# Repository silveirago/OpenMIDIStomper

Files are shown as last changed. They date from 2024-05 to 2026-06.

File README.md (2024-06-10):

# OpenMIDIStomper

## Description
_openMIDIStomper is an Arduino-based MIDI foot controller that provides customizable MIDI message sending capabilities using buttons, potentiometers, and LEDs. It can control any DAW plugin since it's USB MIDI Class compliant. It features 8 stomp buttons and 8 LEDs, all housed in a Hammond aluminum enclosure. The pedalboard has 8 banks, and each button can send up to 5 different messages, configurable through a browser editor.

## Features
- **Button Control:** Send MIDI messages using button presses.
- **Potentiometer Control:** Adjust MIDI parameters with potentiometers.
- **LED Indicators:** Visual feedback using LEDs.
- **Customizable Messages:** Define your own MIDI messages and configurations.

## Watch the Youtube video here:
[Link](https://youtu.be/yELnZdEJqS0)

## Material
 - [1x Arduino Pro Micro](https://amzn.to/3Vg9KrE)
 - [1x Solderable Breadboard](https://amzn.to/4egjUB1)
 - [8x Stomp Buttons](https://amzn.to/3V9GrXu)
 - [8x 5mm Leds](https://amzn.to/3xiPGN9) 
 - [8x 5mm LED Holders](https://amzn.to/4aT8Reh)
 - [2x 1/4" Stereo Socket](https://amzn.to/4aYbtaX)
 - [1x Hammond Enclosure](https://www.aliexpress.us/item/3256805426594939.html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)

## Getting Started

### Prerequisites
- Arduino IDE installed on your computer.
- Arduino board (compatible with the code).
- Necessary components:
  - Push buttons
  - Potentiometers
  - LEDs
  - Resistors
  - Breadboard and jumper wires

### Installation

1. **Clone the Repository:**
   ```sh
   git clone https://github.com/yourusername/_openMIDIStomper.git
   ```

2. **Open the Project:**
   Open the `_openMIDIStomper.ino` file in the Arduino IDE.

## Hardware Setup

### Components and Connections
1. **Buttons:**
   - Connect one terminal of each button in the first row to pin 15.
   - Connect one terminal of each button in the second row to pin 14.
   - Connect the other terminal of the first button in each column to pin 21.
   - Connect the other terminal of the second button in each column to pin 20.
   - Connect the other terminal of the third button in each column to pin 19.
   - Connect the other terminal of the fourth button in each column to pin 16.

2. **Potentiometers:**
   - Connect the middle terminal of each potentiometer to an analog input pin on the Arduino.
   - Connect the other two terminals to 5V and ground, respectively.

3. **LEDs:**

   - **Pins**:  2, 3, 4, 5, 6, 7, 8, 9

#### Connecting LEDs

- **LED 1 (D1)**: Connect the anode to pin 2 through a 220Ω resistor and the cathode to ground.
- **LED 2 (D2)**: Connect the anode to pin 3 through a 220Ω resistor and the cathode to ground.
- **LED 3 (D3)**: Connect the anode to pin 4 through a 220Ω resistor and the cathode to ground.
- **LED 4 (D4)**: Connect the anode to pin 5 through a 220Ω resistor and the cathode to ground.
- **LED 5 (D5)**: Connect the anode to pin 6 through a 220Ω resistor and the cathode to ground.
- **LED 6 (D6)**: Connect the anode to pin 7 through a 220Ω resistor and the cathode to ground.
- **LED 7 (D7)**: Connect the anode to pin 8 through a 220Ω resistor and the cathode to ground.
- **LED 8 (D8)**: Connect the anode to pin 9 through a 220Ω resistor and the cathode to ground.

### Button Matrix

#### Pins Used
- **Rows**: Pins 15 and 14
- **Columns**: Pins 21, 20, 19, and 16

#### Wiring Diagram

- **Button 1 (B1)**: Connect one terminal to pin 15 (Row1) and the other terminal to pin 21 (Column1).
- **Button 2 (B2)**: Connect one terminal to pin 15 (Row1) and the other terminal to pin 20 (Column2).
- **Button 3 (B3)**: Connect one terminal to pin 15 (Row1) and the other terminal to pin 19 (Column3).
- **Button 4 (B4)**: Connect one terminal to pin 15 (Row1) and the other terminal to pin 16 (Column4).

- **Button 5 (B5)**: Connect one terminal to pin 14 (Row2) and the other terminal to pin 21 (Column1).
- **Button 6 (B6)**: Connect one terminal to pin 14 (Row2) and the other terminal to pin 20 (Column2).
- **Button 7 (B7)**: Connect one terminal to pin 14 (Row2) and the other terminal to pin 19 (Column3).
- **Button 8 (B8)**: Connect one terminal to pin 14 (Row2) and the other terminal to pin 16 (Column4).

### Software Configuration

1. **Button Definitions:**
   - Modify `ButtonDefinitions.h` to define the pins and settings for your buttons.

2. **Button Logic:**
   - Implement the logic for button presses in `ButtonLogic.h`.

3. **LED Control:**
   - Adjust the LED control logic in `LEDControl.h`.

4. **MIDI Messages:**
   - Configure the MIDI messages to be sent in `MIDIMessages.h`.

5. **MIDI Out:**
   - Set up the MIDI output in `MIDIOut.h`.

6. **Potentiometer Control:**
   - Define how potentiometer inputs affect MIDI messages in `PotentiometerControl.h`.

## Usage

1. **Upload the Code:**
   - Connect your Arduino board to your computer.
   - Select the appropriate board and port in the Arduino IDE.
   - Upload the `_openMIDIStomper.ino` sketch to the board.

2. **Connect to MIDI Device:**
   - Use a MIDI interface to connect the Arduino to your MIDI device or computer.

3. **Operate:**
   - Press buttons, turn potentiometers, and observe the LED feedback to control your MIDI device.

## Troubleshooting

- Ensure all connections are secure.
- Verify that the correct pins are defined in the header files.
- Check the Arduino IDE for any compilation errors.
- Consult the serial monitor for debugging messages.

## Instructions to Use the MIDI Message Configuration Code Editor

   **Use the editor here**: https://go.musiconerd.com/openmidistomper-editor

1. **Configure the MIDI Messages:**
   - The interface allows you to configure MIDI messages for up to 8 banks, each containing 8 buttons.
   - Each button can send up to 5 different MIDI messages.
   - For each message, you can specify the type (NN, CC, PC, T), the message number (0-127), and the MIDI channel (0-15).

2. **Expand Sections:**
   - Click on the "Bank" buttons to expand and configure each bank.
   - Click on the "Button" buttons within each bank to expand and configure each button's messages.

3. **Pre-fill Values:**
   - By default, the first message for each button is set to Note Number (NN), with the number equal to the button index and the channel equal to the bank index.
   - You can adjust these values as needed.

4. **Copy Configuration:**
   - Once you have configured the MIDI messages, click the "Copy Configuration to Clipboard" button.
   - A message will appear indicating that the configuration has been copied to your clipboard.

5. **Paste into Arduino Sketch:**
   - Open your Arduino sketch in the Arduino IDE.
   - Paste the copied configuration code into the appropriate section of your sketch.

6. **Export and Import Bank Configurations:**
   - To export a bank's configuration, click the "Export Bank Configuration" button for the desired bank. This will download a text file with the configuration.
   - To import a bank's configuration, click the "Import Bank Configuration" button for the desired bank and select the previously exported configuration file.

7. **Save and Upload:**
   - Save the changes in your Arduino sketch.
   - Upload the sketch to your Arduino board to use the configured MIDI messages.

This HTML code editor provides a user-friendly interface to configure and manage MIDI messages, making it easy to set up your MIDI controller.

## How to Upload Your Presets

### Method 1: Using GitHub Issues

1. **Go to the Issues Tab**: Navigate to the Issues tab of the repository.

2. **Create a New Issue**:
    - Click on the "New Issue" button.
    - Provide a descriptive title for your issue, such as "New Preset: [Preset Name]".
    - In the description, provide any relevant details about your preset.

3. **Attach Your Preset File**:
    - Drag and drop your preset file into the issue description area or click the "Attach files by dragging & dropping, selecting or pasting them." link.
    - Ensure the file uploads successfully.

4. **Submit the Issue**:
    - Click the "Submit new issue" button to create the issue.

Thank you! We will review your preset and integrate it into the repository.

### Method 2: Using Pull Requests (Advanced Users)

1. **Fork the Repository**:
    - Click the "Fork" button at the top right of the repository page to create a copy of the repository under your GitHub account.

2. **Clone the Repository**:
    - Clone your forked repository to your local machine using the following command:
      ```sh
      git clone https://github.com/YOUR-USERNAME/REPOSITORY-NAME.git
      ```
    - Replace \`YOUR-USERNAME\` with your GitHub username and \`REPOSITORY-NAME\` with the name of the repository.

3. **Create a New Branch**:
    - Navigate to the repository directory on your local machine:
      ```sh
      cd REPOSITORY-NAME
      ```
    - Create a new branch for your changes:
      ```sh
      git checkout -b new-preset-branch
      ```

4. **Add Your Preset File**:
    - Add your preset file to the appropriate directory (e.g., \`presets/\`):
      ```sh
      cp /path/to/your/preset/file presets/
      ```

5. **Commit Your Changes**:
    - Stage your changes:
      ```sh
      git add presets/your-preset-file
      ```
    - Commit your changes with a descriptive message:
      ```sh
      git commit -m "Add new preset: [Preset Name]"
      ```

6. **Push Your Changes**:
    - Push your changes to your forked repository:
      ```sh
      git push origin new-preset-branch
      ```

7. **Create a Pull Request**:
    - Navigate to your forked repository on GitHub.
    - Click the "Compare & pull request" button next to your new branch.
    - Provide a descriptive title and description for your pull request.
    - Click "Create pull request".

We will review your pull request and merge it if everything looks good. Thank you for your contribution!

Feel free to reach out via the [Discussions] https://github.com/silveirago/OpenMIDIStomper/discussions tab if you have any questions or need further assistance. Happy contributing!

## Contributing

Feel free to contribute to this project by submitting issues or pull requests. Any improvements or bug fixes are welcome.

## License

This project is licensed under the MIT License. See the LICENSE file for details.

## Acknowledgements

Thank you to the open-source community for providing valuable resources and inspiration for this project.

## Support this Project

This project was created by me, Gustavo Silveira, a.k.a. the Nerd Musician, for the community.

If you want to support me, so I can keep doing projects like this, consider buying one of my DIY MIDI Controller courses: https://go.musiconerd.com/nerd-musician-pro

Or PayPal me any ammount here: https://www.paypal.com/paypalme/nerdmusician

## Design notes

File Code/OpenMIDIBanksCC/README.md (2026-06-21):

# OpenMIDIBanksCC

Standalone OpenMIDIStomper firmware variant that preserves the original bank, button, LED, and matrix interaction model while changing only the outgoing MIDI assignments.

## Behavior Summary

- Short press + release sends one CC with value `127`.
- The button action uses the bank that was active when the press started.
- Long press for 1 second selects the corresponding bank.
- Long-press bank selection suppresses the button action.
- Idle LEDs show the active bank exactly like the original firmware.
- `A0` is an optional compile-time expression pedal input.
- `A10` is an optional compile-time sustain pedal input.
- MIDI channel is `16`.

## Hardware Reference

- Rows: `15, 14`
- Columns: `21, 20, 19, 16`
- LEDs: `2, 3, 4, 5, 6, 7, 8, 9`
- Expression: `A0`
- Sustain: optional `A10`
- LEDs are active-high.

Buttons are scanned as a `2x4` matrix with row pins driven `HIGH` at idle and pulled `LOW` one at a time during scan. Column pins use `INPUT_PULLUP`, so a pressed switch reads `LOW`.

## CC Table

| Bank | Buttons | A0 |
|---|---|---|
| 1 | `56, 57, 58, 59, 60, 61, 62, 63` | `64` |
| 2 | `65, 66, 67, 68, 69, 70, 71, 72` | `73` |
| 3 | `74, 75, 76, 77, 78, 79, 80, 81` | `82` |
| 4 | `83, 84, 85, 86, 87, 88, 89, 90` | `91` |
| 5 | `92, 93, 94, 95, 96, 97, 98, 99` | `100` |
| 6 | `101, 102, 103, 104, 105, 106, 107, 108` | `109` |
| 7 | `110, 111, 112, 113, 114, 115, 116, 117` | `118` |
| 8 | `119, 120, 121, 122, 123, 124, 125, 126` | `127` |

## Compile-Time Pedal Options

At the top of the sketch:

```cpp
#define ENABLE_EXPRESSION_A0  1
#define ENABLE_SUSTAIN_A10    1
```

- Enable A0: set `#define ENABLE_EXPRESSION_A0  1`
- Disable A0: set `#define ENABLE_EXPRESSION_A0  0`
- Enable sustain on A10: set `#define ENABLE_SUSTAIN_A10    1`
- Disable sustain on A10: set `#define ENABLE_SUSTAIN_A10    0`

These are compile-time options implemented with preprocessor conditionals. When a pedal feature is disabled, its state variables, reads, processing, and MIDI output are excluded from the compiled firmware, which reduces firmware size.

## Sustain Pedal (A10)

- Optional compile-time feature
- Uses `INPUT_PULLUP`
- Pedal connected between `A10` and `GND`
- Sends `CC 47`
- Press = `127`
- Release = `0`
- One message on press, one on release, with no repeats while held
- Independent from banks
- Independent from the `A0` expression pedal
- Independent from the button matrix

Verification targets:

- Press pedal -> `CC47` value `127`
- Hold pedal -> no additional messages
- Release pedal -> `CC47` value `0`
- Bank changes do not affect sustain behavior
- `A0` expression remains unchanged
- Original button-bank behavior remains unchanged

## Upload / Compile

Required library:

- `MIDIUSB`

Target board:

- SparkFun Pro Micro 5V/16MHz

CLI steps:

```sh
arduino-cli core install SparkFun:avr \
  --additional-urls https://raw.githubusercontent.com/sparkfun/Arduino_Boards/master/IDE_Board_Manager/package_sparkfun_index.json
arduino-cli compile --fqbn SparkFun:avr:promicro:cpu=16MHzatmega32U4 \
  --additional-urls https://raw.githubusercontent.com/sparkfun/Arduino_Boards/master/IDE_Board_Manager/package_sparkfun_index.json \
  Code/OpenMIDIBanksCC
```

## Isolation Statement

- No files in `Code/_openMIDIStomper/` were modified.
- No files in `Code/SimpleMIDIMatrix/` were modified by this variant.
- This firmware lives entirely inside `Code/OpenMIDIBanksCC/`.

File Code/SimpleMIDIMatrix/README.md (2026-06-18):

# SimpleMIDIMatrix

A minimal, self-contained MIDI firmware for the **OpenMIDIStomper** hardware
(Arduino Pro Micro, ATmega32U4).  
It lives alongside the original firmware without touching it.

---

## What it does

| Event | Action |
|---|---|
| Button pressed | Sends **Note On** (velocity 127) |
| Button released | Sends **Note Off** (velocity 0) |
| Incoming Note On (vel > 0) | Turns the matching **LED on** |
| Incoming Note Off / Note On vel 0 | Turns the matching **LED off** |

Each button sends exactly **one** Note On on press and **one** Note Off on release.  
LEDs reflect both local presses and incoming MIDI feedback from a DAW/host.

---

## Default MIDI mapping

| Button | Row | Col | Arduino pin (LED) | MIDI Note |
|---|-----|-----|---|---|
| 1 | 0 | 0 | 2 | 36 (C2) |
| 2 | 0 | 1 | 3 | 37 (C#2) |
| 3 | 0 | 2 | 4 | 38 (D2) |
| 4 | 0 | 3 | 5 | 39 (D#2) |
| 5 | 1 | 0 | 6 | 40 (E2) |
| 6 | 1 | 1 | 7 | 41 (F2) |
| 7 | 1 | 2 | 8 | 42 (F#2) |
| 8 | 1 | 3 | 9 | 43 (G2) |

MIDI channel: **1**

---

## Hardware pin reference

```
Row pins  (OUTPUT, driven LOW to scan) : 15, 14
Col pins  (INPUT_PULLUP, reads LOW)    : 21, 20, 19, 16
LED pins  (OUTPUT, active HIGH)        : 2, 3, 4, 5, 6, 7, 8, 9
```

Buttons are wired between a row pin and a column pin — no external pull-up
resistors needed. LEDs have their anode connected to the LED pin through a
220 Ω resistor; cathode to GND.

---

## How to upload

1. Open **Arduino IDE**.
2. **File → Open** → navigate to `Code/SimpleMIDIMatrix/SimpleMIDIMatrix.ino`.
3. **Tools → Board** → select **Arduino Leonardo** (or Pro Micro if you have the
   SparkFun board package installed).
4. **Tools → Port** → choose the COM/serial port for your Pro Micro.
5. Click **Upload** (→).

> ⚠️ Do **not** open the original `_openMIDIStomper.ino` at the same time.  
> Each sketch lives in its own folder and is completely independent.

---

## How to change MIDI notes

Open `SimpleMIDIMatrix.ino` and find the `noteNumbers` array near the top of
the **USER-CONFIGURABLE SECTION**:

```cpp
const byte noteNumbers[8] = { 36, 37, 38, 39, 40, 41, 42, 43 };
//                            Btn1 Btn2 Btn3 Btn4 Btn5 Btn6 Btn7 Btn8
```

Replace any value with the desired MIDI note number (0–127) and re-upload.

---

## How to change the MIDI channel

Find the `MIDI_CHANNEL` constant:

```cpp
const byte MIDI_CHANNEL = 1;   // 1–16
```

Change `1` to any value from `1` to `16` and re-upload.

---

## How to change pins

### Row pins
```cpp
const byte rowPins[2] = { 15, 14 };
//                         Row0 Row1
```

### Column pins
```cpp
const byte colPins[4] = { 21, 20, 19, 16 };
//                         Col0 Col1 Col2 Col3
```

### LED pins
```cpp
const byte ledPins[8] = { 2, 3, 4, 5, 6, 7, 8, 9 };
//                        Btn1 ... Btn8
```

Button index order is `row * 4 + col`, so:
- Index 0 = Row 0, Col 0 (Button 1)
- Index 4 = Row 1, Col 0 (Button 5)

---

## How to change debounce time

```cpp
const unsigned long DEBOUNCE_MS = 10;  // milliseconds
```

Increase this value if you get false double-triggers on noisy switches.

---

## Isolation from the original firmware

This sketch is **completely independent**:

- It has no `#include` of any header from `_openMIDIStomper/` or
  `_openMIDIStomper_2/`.
- It declares its own variables and functions; nothing is shared.
- The Arduino IDE treats each folder as a separate project. Opening
  `SimpleMIDIMatrix.ino` loads **only** this sketch.
- The original firmware files are unchanged.

---

## Required library

**MIDIUSB** — included with the Arduino AVR boards package for 32U4-based
boards (Leonardo, Pro Micro).  
Install via **Tools → Manage Libraries → search "MIDIUSB"** if not present.

---

*Created by Gustavo Silveira / Nerd Musician — simplified variant of
OpenMIDIStomper.*

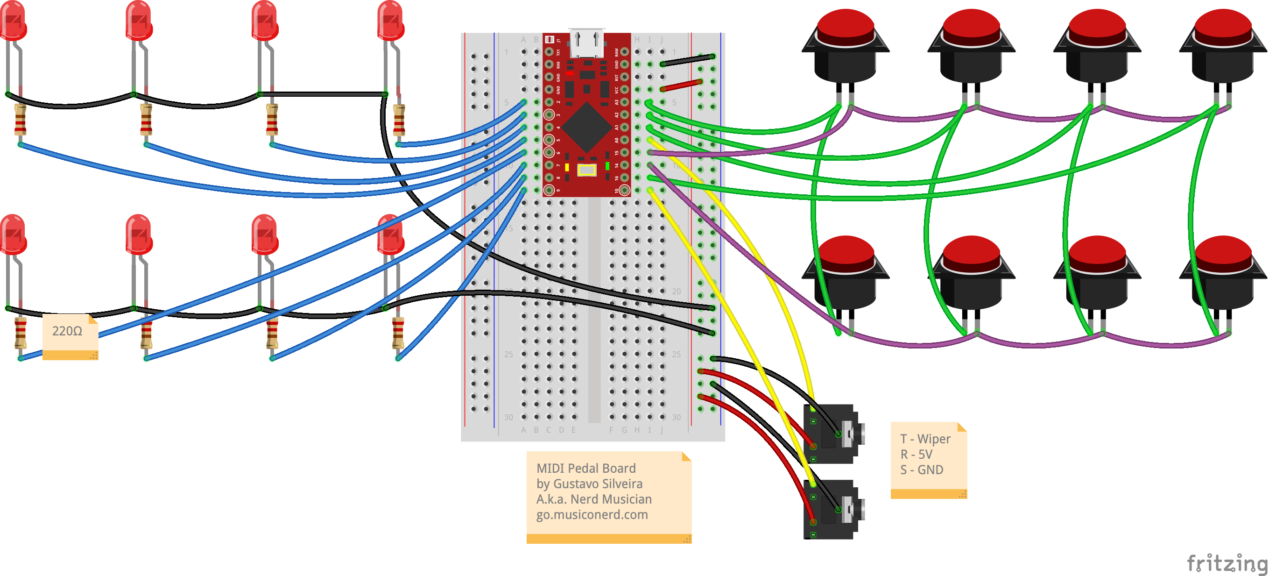
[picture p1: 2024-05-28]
Schematic/openMIDIStomper_bb.png

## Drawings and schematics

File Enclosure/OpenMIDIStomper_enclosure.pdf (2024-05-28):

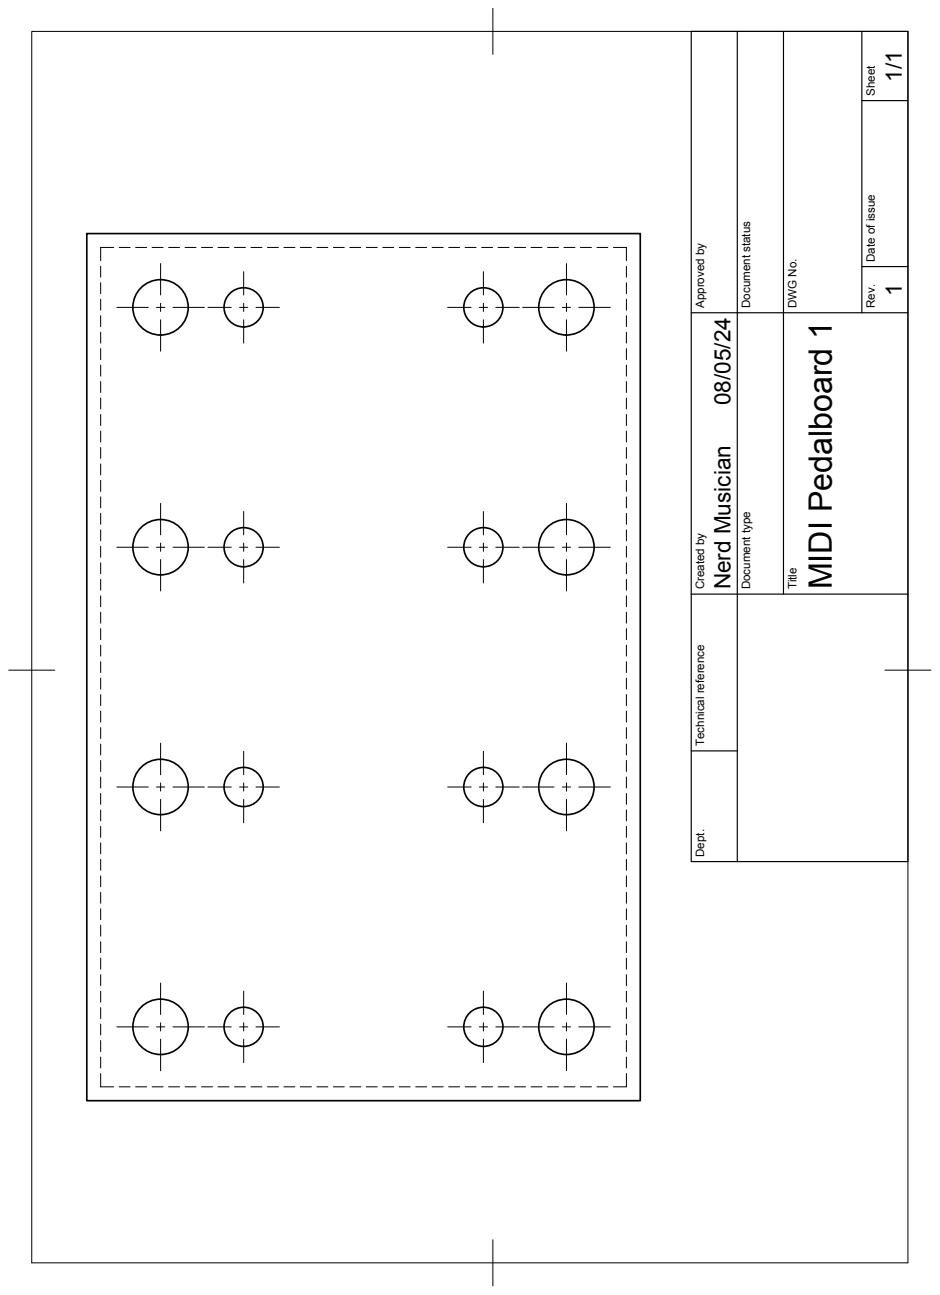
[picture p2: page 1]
Nerd Musician; MIDI Pedalboard 1

Rev. Date of issue Sheet

Document type Document status

Dept. Technical reference Created by Approved by

Title DWG No.

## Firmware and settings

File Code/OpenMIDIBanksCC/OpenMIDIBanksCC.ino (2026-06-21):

#include <MIDIUSB.h>

//#define ENABLE_EXPRESSION_A0  1
#define ENABLE_SUSTAIN_A10    1

const byte MIDI_CHANNEL = 16;

const byte NUM_ROWS = 2;
const byte NUM_COLS = 4;
const byte N_BUTTONS = 8;
const byte N_BANKS = 8;
const byte N_LEDS = 8;

const byte rowPins[NUM_ROWS] = { 15, 14 };
const byte colPins[NUM_COLS] = { 21, 20, 19, 16 };
const byte ledPins[N_LEDS] = { 2, 3, 4, 5, 6, 7, 8, 9 };

const unsigned long DEBOUNCE_DELAY = 10;
const unsigned long LONG_PRESS_DURATION = 1000;
const int ANALOG_JITTER_THRESHOLD = 4;
const unsigned long ANALOG_ACTIVITY_TIMEOUT = 300;
const unsigned long SUSTAIN_DEBOUNCE_MS = 20;
const byte SUSTAIN_CC = 47;

const byte buttonCCs[N_BANKS][N_BUTTONS] = {
  { 56, 57, 58, 59, 60, 61, 62, 63 },
  { 65, 66, 67, 68, 69, 70, 71, 72 },
  { 74, 75, 76, 77, 78, 79, 80, 81 },
  { 83, 84, 85, 86, 87, 88, 89, 90 },
  { 92, 93, 94, 95, 96, 97, 98, 99 },
  { 101, 102, 103, 104, 105, 106, 107, 108 },
  { 110, 111, 112, 113, 114, 115, 116, 117 },
  { 119, 120, 121, 122, 123, 124, 125, 126 }
};

const byte expressionCCs[N_BANKS] = { 64, 73, 82, 91, 100, 109, 118, 127 };

int currentBank = 0;
byte buttonCState[N_BUTTONS] = { 0 };
byte buttonPState[N_BUTTONS] = { 0 };
int buttonBankAtPress[N_BUTTONS] = { 0 };
unsigned long buttonPressStartTime[N_BUTTONS] = { 0 };
bool longPressDetected[N_BUTTONS] = { false };
bool isAnyButtonPressed = false;
unsigned long lastDebounceTime[N_BUTTONS] = { 0 };

#if ENABLE_EXPRESSION_A0
const byte expressionA0Pin = A0;
int lastAnalogRaw = 0;
byte lastAnalogMidi = 255;
unsigned long analogMoveTimestamp = 0;
#endif

#if ENABLE_SUSTAIN_A10
const byte sustainPin = A10;
bool sustainState = HIGH;
bool sustainLastReading = HIGH;
unsigned long sustainLastDebounceTime = 0;
#endif

void updateLEDs();
void scanButtonMatrix();
void handleButtonState(byte index);
void sendControlChange(byte control, byte value);

#if ENABLE_EXPRESSION_A0
void handleExpressionA0();
#endif

#if ENABLE_SUSTAIN_A10
void handleSustainPedal();
#endif

void setup() {
  for (byte row = 0; row < NUM_ROWS; ++row) {
    pinMode(rowPins[row], OUTPUT);
    digitalWrite(rowPins[row], HIGH);
  }

  for (byte col = 0; col < NUM_COLS; ++col) {
    pinMode(colPins[col], INPUT_PULLUP);
  }

  for (byte led = 0; led < N_LEDS; ++led) {
    pinMode(ledPins[led], OUTPUT);
    digitalWrite(ledPins[led], LOW);
  }

#if ENABLE_EXPRESSION_A0
  lastAnalogRaw = analogRead(expressionA0Pin);
  lastAnalogMidi = map(lastAnalogRaw, 0, 1023, 0, 127);
  analogMoveTimestamp = millis();
#endif

#if ENABLE_SUSTAIN_A10
  pinMode(sustainPin, INPUT_PULLUP);
#endif

  updateLEDs();
}

void loop() {
  scanButtonMatrix();

  if (!isAnyButtonPressed) {
    updateLEDs();
  }

#if ENABLE_EXPRESSION_A0
  handleExpressionA0();
#endif

#if ENABLE_SUSTAIN_A10
  handleSustainPedal();
#endif
}

void scanButtonMatrix() {
  for (byte row = 0; row < NUM_ROWS; ++row) {
    digitalWrite(rowPins[row], LOW);

    for (byte col = 0; col < NUM_COLS; ++col) {
      byte index = row * NUM_COLS + col;

      if (digitalRead(colPins[col]) == LOW) {
        buttonCState[index] = 1;

        if (buttonPState[index] == 0) {
          buttonPressStartTime[index] = millis();
          longPressDetected[index] = false;
          buttonBankAtPress[index] = currentBank;
        }
      } else {
        buttonCState[index] = 0;
      }

      handleButtonState(index);
    }

    digitalWrite(rowPins[row], HIGH);
  }

  bool anyPressed = false;
  for (byte index = 0; index < N_BUTTONS; ++index) {
    if (buttonPState[index] > 0) {
      anyPressed = true;
      break;
    }
  }
  isAnyButtonPressed = anyPressed;
}

void handleButtonState(byte index) {
  unsigned long now = millis();
  if ((now - lastDebounceTime[index]) <= DEBOUNCE_DELAY) {
    return;
  }

  lastDebounceTime[index] = now;

  if (buttonPState[index] != buttonCState[index]) {
    if (buttonCState[index] > 0) {
      digitalWrite(ledPins[index], HIGH);
    } else {
      digitalWrite(ledPins[index], LOW);

      if (!longPressDetected[index]) {
        sendControlChange(buttonCCs[buttonBankAtPress[index]][index], 127);
      }
    }

    buttonPState[index] = buttonCState[index];
  } else if (buttonCState[index] > 0 && !longPressDetected[index]) {
    if ((now - buttonPressStartTime[index]) >= LONG_PRESS_DURATION) {
      longPressDetected[index] = true;
      currentBank = index;
      updateLEDs();
    }
  }
}

void updateLEDs() {
  for (byte led = 0; led < N_LEDS; ++led) {
    digitalWrite(ledPins[led], LOW);
  }

  if (currentBank >= 0 && currentBank < N_LEDS) {
    digitalWrite(ledPins[currentBank], HIGH);
  }
}

#if ENABLE_EXPRESSION_A0
void handleExpressionA0() {
  unsigned long now = millis();
  int raw = analogRead(expressionA0Pin);
  int rawDelta = abs(raw - lastAnalogRaw);

  if (rawDelta > ANALOG_JITTER_THRESHOLD) {
    analogMoveTimestamp = now;
    lastAnalogRaw = raw;
  }

  byte midiValue = map(raw, 0, 1023, 0, 127);

  if ((now - analogMoveTimestamp) < ANALOG_ACTIVITY_TIMEOUT) {
    if (midiValue != lastAnalogMidi) {
      sendControlChange(expressionCCs[currentBank], midiValue);
      lastAnalogMidi = midiValue;
    }
  }
}
#endif

#if ENABLE_SUSTAIN_A10
void handleSustainPedal() {
  unsigned long now = millis();
  bool reading = digitalRead(sustainPin);

  if (reading != sustainLastReading) {
    sustainLastDebounceTime = now;
    sustainLastReading = reading;
  }

  if ((now - sustainLastDebounceTime) >= SUSTAIN_DEBOUNCE_MS) {
    if (reading != sustainState) {
      sustainState = reading;
      if (sustainState == LOW) {
        sendControlChange(SUSTAIN_CC, 127);
      } else {
        sendControlChange(SUSTAIN_CC, 0);
      }
    }
  }
}
#endif

void sendControlChange(byte control, byte value) {
  midiEventPacket_t event = {
    0x0B,
    (uint8_t)(0xB0 | ((MIDI_CHANNEL - 1) & 0x0F)),
    control,
    value
  };

  MidiUSB.sendMIDI(event);
  MidiUSB.flush();
}

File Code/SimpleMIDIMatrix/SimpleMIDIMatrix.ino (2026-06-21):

// =============================================================================
//  SimpleMIDIMatrix.ino
//  Minimal MIDI matrix firmware for OpenMIDIStomper hardware.
//
//  Default behavior:
//    - 8 buttons send Control Change messages
//    - MIDI Channel 16
//    - CC numbers 102–109
//
//  Note support is still kept in the code.
// =============================================================================

#include <MIDIUSB.h>

// ---------------------------------------------------------------------------
//  USER-CONFIGURABLE SECTION
// ---------------------------------------------------------------------------

const byte MIDI_CHANNEL = 16;

const byte rowPins[2] = { 15, 14 };
const byte colPins[4] = { 21, 20, 19, 16 };

const byte ledPins[8] = { 2, 3, 4, 5, 6, 7, 8, 9 };

enum MidiMessageType {
  MIDI_NOTE,
  MIDI_CC
};

// Default: all buttons send CC.
// To make a button send a note, change MIDI_CC to MIDI_NOTE for that index.
const MidiMessageType buttonTypes[8] = {
  MIDI_CC,
  MIDI_CC,
  MIDI_CC,
  MIDI_CC,
  MIDI_CC,
  MIDI_CC,
  MIDI_CC,
  MIDI_CC
};

// If buttonTypes[i] is MIDI_CC, this is the CC number.
// If buttonTypes[i] is MIDI_NOTE, this is the note number.
const byte midiNumbers[8] = {
  102, 103, 104, 105,
  106, 107, 108, 109
};

const byte NOTE_ON_VELOCITY = 127;

const byte CC_ON_VALUE = 127;
const byte CC_OFF_VALUE = 0;

const unsigned long DEBOUNCE_MS = 10;

// ---------------------------------------------------------------------------
//  INTERNAL STATE
// ---------------------------------------------------------------------------

byte buttonCurrentState[8] = { 0 };
unsigned long lastDebounceTime[8] = { 0 };
byte rawState[8] = { 0 };
byte ledState[8] = { 0 };

// ---------------------------------------------------------------------------
//  SETUP
// ---------------------------------------------------------------------------

void setup() {
  for (int r = 0; r < 2; r++) {
    pinMode(rowPins[r], OUTPUT);
    digitalWrite(rowPins[r], HIGH);
  }

  for (int c = 0; c < 4; c++) {
    pinMode(colPins[c], INPUT_PULLUP);
  }

  for (int i = 0; i < 8; i++) {
    pinMode(ledPins[i], OUTPUT);
    digitalWrite(ledPins[i], LOW);
  }
}

// ---------------------------------------------------------------------------
//  MAIN LOOP
// ---------------------------------------------------------------------------

void loop() {
  scanMatrix();
  readMidiInput();
}

// ---------------------------------------------------------------------------
//  MATRIX SCAN WITH DEBOUNCE AND EDGE DETECTION
// ---------------------------------------------------------------------------

void scanMatrix() {
  for (int row = 0; row < 2; row++) {
    digitalWrite(rowPins[row], LOW);

    for (int col = 0; col < 4; col++) {
      int idx = row * 4 + col;
      byte reading = (digitalRead(colPins[col]) == LOW) ? 1 : 0;

      if (reading != rawState[idx]) {
        lastDebounceTime[idx] = millis();
        rawState[idx] = reading;
      }

      if ((millis() - lastDebounceTime[idx]) >= DEBOUNCE_MS) {
        if (reading != buttonCurrentState[idx]) {
          buttonCurrentState[idx] = reading;

          if (reading == 1) {
            sendButtonOn(idx);
            setLED(idx, 1);
          } else {
            sendButtonOff(idx);
            setLED(idx, 0);
          }
        }
      }
    }

    digitalWrite(rowPins[row], HIGH);
  }
}

// ---------------------------------------------------------------------------
//  INCOMING MIDI HANDLER
// ---------------------------------------------------------------------------

void readMidiInput() {
  midiEventPacket_t rx;

  do {
    rx = MidiUSB.read();

    if (rx.header != 0) {
      byte statusByte = rx.byte1;
      byte msgType = statusByte & 0xF0;
      byte channel = statusByte & 0x0F;
      byte number = rx.byte2;
      byte value = rx.byte3;

      if (channel != (MIDI_CHANNEL - 1)) continue;

      if (msgType == 0x90) {
        setLEDForMidiMessage(MIDI_NOTE, number, value > 0 ? 1 : 0);
      } else if (msgType == 0x80) {
        setLEDForMidiMessage(MIDI_NOTE, number, 0);
      } else if (msgType == 0xB0) {
        setLEDForMidiMessage(MIDI_CC, number, value > 0 ? 1 : 0);
      }
    }
  } while (rx.header != 0);
}

// ---------------------------------------------------------------------------
//  BUTTON MIDI DISPATCH
// ---------------------------------------------------------------------------

void sendButtonOn(int idx) {
  if (buttonTypes[idx] == MIDI_NOTE) {
    sendNoteOn(midiNumbers[idx]);
  } else {
    sendControlChange(midiNumbers[idx], CC_ON_VALUE);
  }
}

void sendButtonOff(int idx) {
  if (buttonTypes[idx] == MIDI_NOTE) {
    sendNoteOff(midiNumbers[idx]);
  } else {
    sendControlChange(midiNumbers[idx], CC_OFF_VALUE);
  }
}

// ---------------------------------------------------------------------------
//  MIDI OUTPUT HELPERS
// ---------------------------------------------------------------------------

void sendNoteOn(byte note) {
  midiEventPacket_t pkt = {
    0x09,
    (uint8_t)(0x90 | (MIDI_CHANNEL - 1)),
    note,
    NOTE_ON_VELOCITY
  };

  MidiUSB.sendMIDI(pkt);
  MidiUSB.flush();
}

void sendNoteOff(byte note) {
  midiEventPacket_t pkt = {
    0x08,
    (uint8_t)(0x80 | (MIDI_CHANNEL - 1)),
    note,
    0
  };

  MidiUSB.sendMIDI(pkt);
  MidiUSB.flush();
}

void sendControlChange(byte ccNumber, byte value) {
  midiEventPacket_t pkt = {
    0x0B,
    (uint8_t)(0xB0 | (MIDI_CHANNEL - 1)),
    ccNumber,
    value
  };

  MidiUSB.sendMIDI(pkt);
  MidiUSB.flush();
}

// ---------------------------------------------------------------------------
//  LED HELPERS
// ---------------------------------------------------------------------------

void setLED(int idx, byte state) {
  ledState[idx] = state;
  digitalWrite(ledPins[idx], state ? HIGH : LOW);
}

void setLEDForMidiMessage(MidiMessageType type, byte number, byte state) {
  for (int i = 0; i < 8; i++) {
    if (buttonTypes[i] == type && midiNumbers[i] == number) {
      setLED(i, state);
    }
  }
}

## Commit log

2024-05-28 files added
    [openMIDIStomper.fzz]
2024-05-29 basic config preset added
    [bank_basic_config.txt]
